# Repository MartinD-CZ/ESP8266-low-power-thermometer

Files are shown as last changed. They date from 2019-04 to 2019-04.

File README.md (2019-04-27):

# ESP8266 ultra low power thermometer
*see the article [here](http://embedblog.eu/?p=36)*
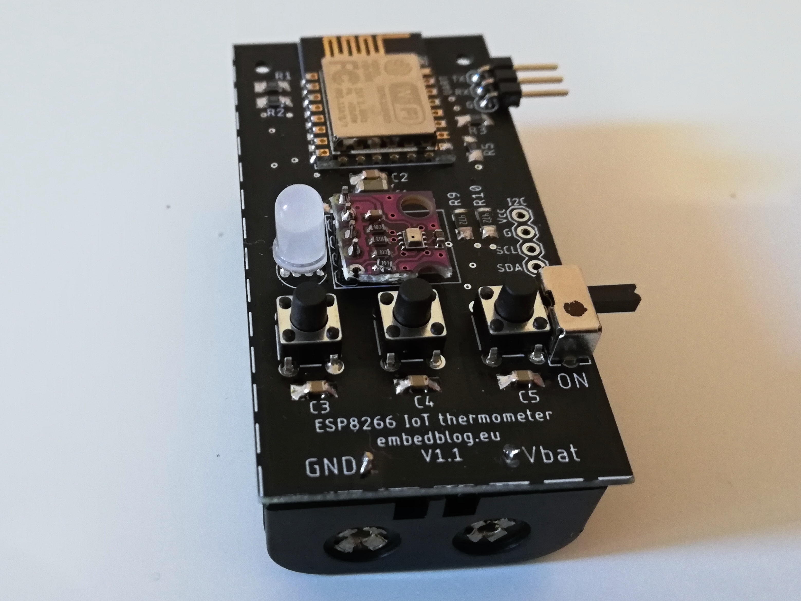
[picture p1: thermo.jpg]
A picture of the finished thermometer


## Specs
1. Arduino-compatible
2. lasts more than 2 years on a pair of AA batteries
3. measures temperature and pressure (BMP280) OR temperature, humidity and pressure (BME280)
4. transmits data regularly to Blynk (or other platform, if you program it for it)
5. can be programmed with just a simple USB-Serial converter

## Required libraries
* [ESP8266 core](https://github.com/esp8266/Arduino)
* [Blynk library](https://github.com/blynkkk/blynk-library)
* [BMP280 library](https://github.com/mahfuz195/BMP280-Arduino-Library)

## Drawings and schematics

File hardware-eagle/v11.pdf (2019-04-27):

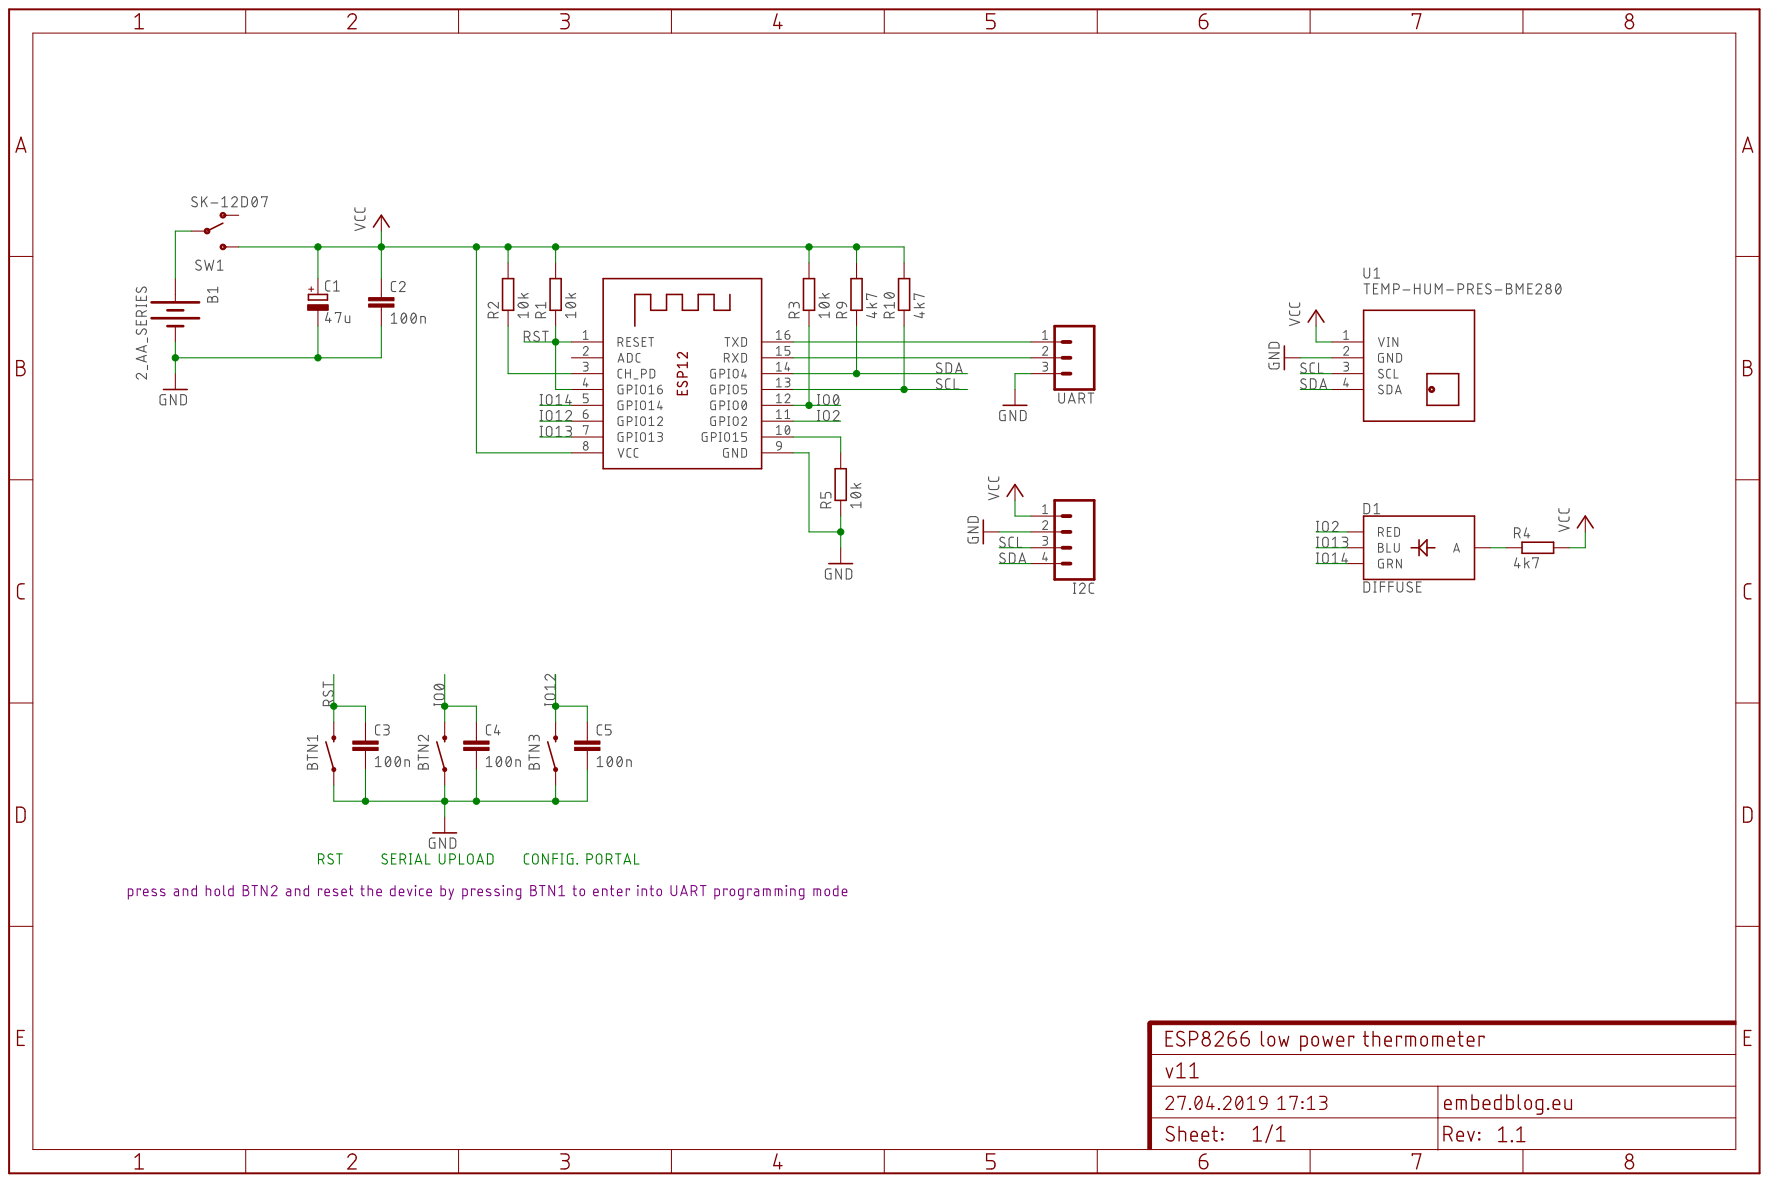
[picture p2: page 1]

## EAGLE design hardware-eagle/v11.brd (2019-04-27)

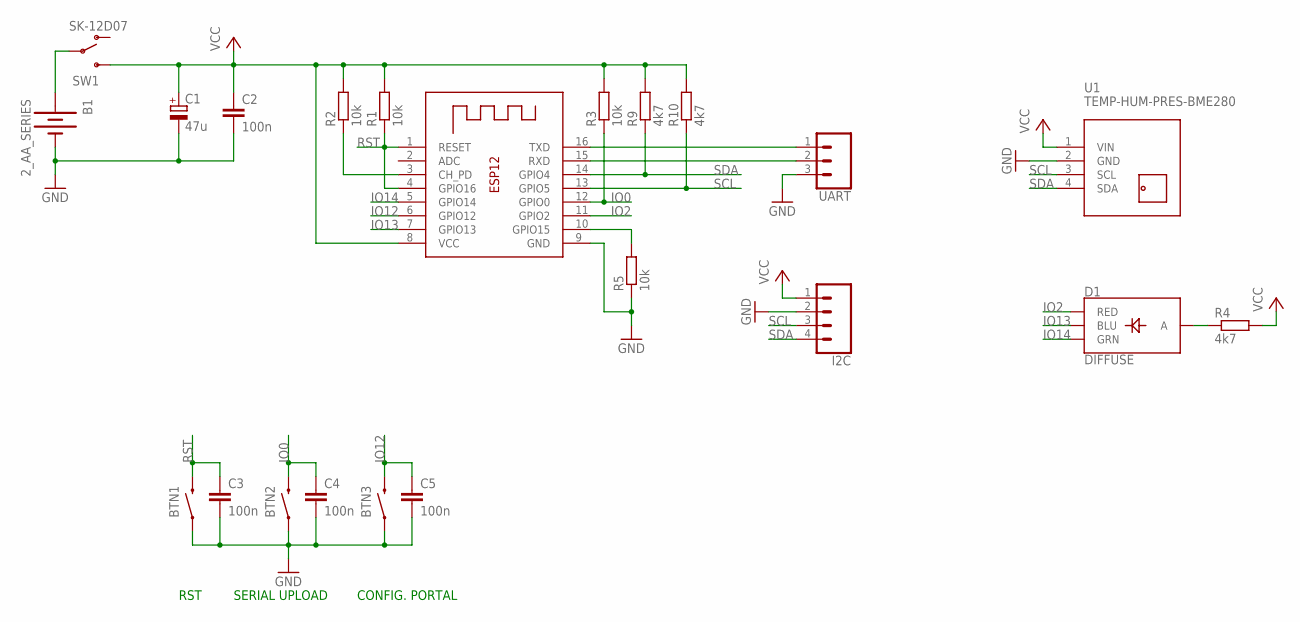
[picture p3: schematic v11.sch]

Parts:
B1: 2_AA_SERIES; AA_HOLDER_BH-321-1P
BTN1, BTN2, BTN3: MOMENTARY-SWITCH-SPST-PTH-6.0MM; TACTILE_SWITCH_PTH_6.0MM
C1: 47u; SMC_B
C2, C3, C4, C5: 100n; C1206
D1: DIFFUSE; LED-RGB-THRU
I2C: CONN_04; 1X04
R1, R2, R3, R5: 10k; R1206
R4, R9, R10: 4k7; R1206
SW1: SK-12D07; SK12SWITCH
U1: TEMP-HUM-PRES-BME280
UART: 455-1750-1-ND; 1X03
X1: ESP-12

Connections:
GND: B1.NEG (-), BTN1.1, BTN2.1, BTN3.1, C1.-, C2.2, C3.2, C4.2, C5.2, I2C.2, R5.1, U1.2 (GND), UART.3, X1.9 (GND)
IO0: BTN2.3 (2), C4.1, R3.1, X1.12 (GPIO0)
IO2: D1.1 (RED), X1.11 (GPIO2)
IO12: BTN3.3 (2), C5.1, X1.6 (GPIO12)
IO13: D1.4 (BLU), X1.7 (GPIO13)
IO14: D1.3 (GRN), X1.5 (GPIO14)
unnamed: D1.2 (A), R4.1
unnamed: R2.1, X1.3 (CH_PD)
unnamed: R5.2, X1.10 (GPIO15)
unnamed: B1.POS (+), SW1.P2
RST: BTN1.3 (2), C3.1, R1.1, X1.1 (RESET), X1.4 (GPIO16)
RX: UART.2, X1.15 (RXD)
SCL: I2C.3, R10.1, U1.3 (SCL), X1.13 (GPIO5)
SDA: I2C.4, R9.1, U1.4 (SDA), X1.14 (GPIO4)
TX: UART.1, X1.16 (TXD)
VCC: C1.+, C2.1, I2C.1, R1.2, R2.2, R3.2, R4.2, R9.2, R10.2, SW1.IN (S), U1.1 (VIN), X1.8 (VCC)

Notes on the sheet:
RST
SERIAL UPLOAD
CONFIG. PORTAL

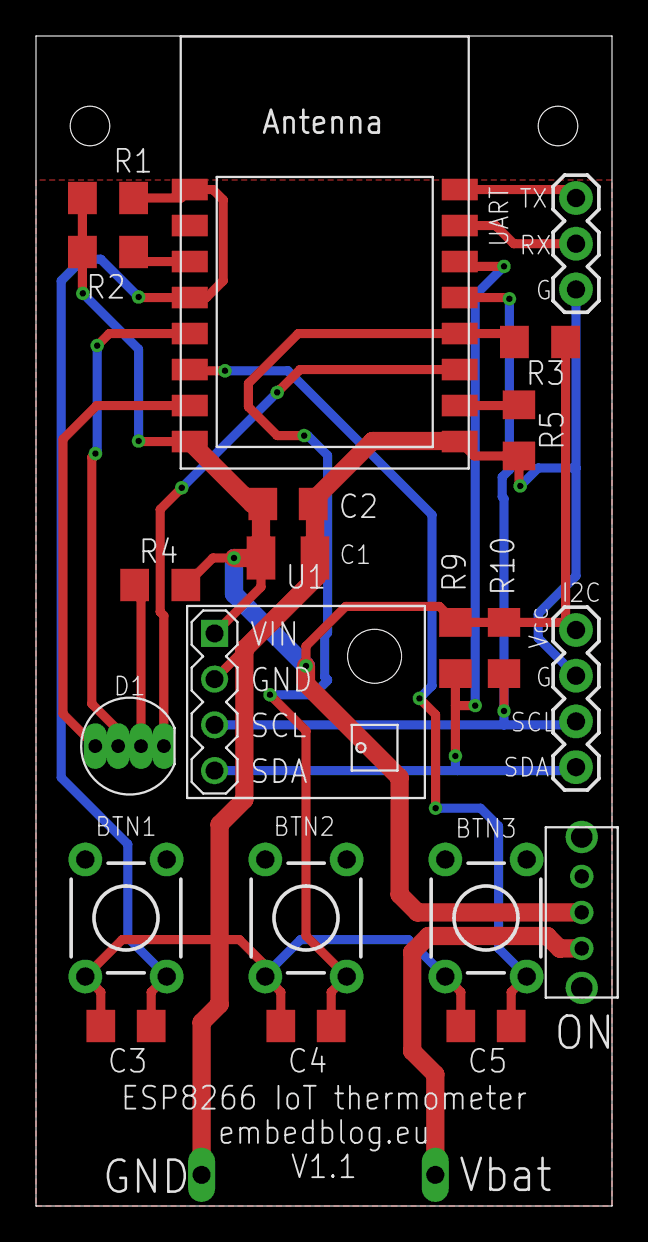
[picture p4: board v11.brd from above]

Board: 2 copper layers, 32.0 x 65.0 mm, 22 parts (1 on the bottom side), 16 nets.

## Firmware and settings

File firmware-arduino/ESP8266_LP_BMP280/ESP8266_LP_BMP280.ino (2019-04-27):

#define DEBUG_SERIAL
#ifdef DEBUG_SERIAL
#define DBG_PRINT(x)    Serial.print(x)
#define DBG_PRINTLN(x)  Serial.println(x)
#define BLYNK_PRINT Serial
#else
#define DBG_PRINT(x)
#define DBG_PRINTLN(x)
#endif

#include <ESP8266WiFi.h>
#include <BlynkSimpleEsp8266.h>

#include <Wire.h>
#include "BMP280.h"
BMP280 bmp;

#define RTC_VALID_DATA  0xC4
typedef struct rtc {
  uint8_t dataValidation;
  int32_t messageID;
};
rtc rtcMem;

ADC_MODE(ADC_VCC);

// CONFIG PART
// modify the below to set parameters

#define DEEPSLEEP_INTERVAL    60    //in minutes
#define MSGID_VWIRE           V0
#define BATT_VWIRE            V1
#define TEMP_VWIRE            V2
#define HUM_VWIRE             V3
#define PRES_VWIRE            V4

char* ssid = "";
char* pass = "";
char* auth = "";

void setup() 
{
  gpio_init();
  DBG_PRINTLN("");
  DBG_PRINTLN("Device started");

  if (bmp.begin(5, 4))
    {
      DBG_PRINTLN("BMP/BME sensor successfully initialized");
      bmp.setOversampling(4);
    }
    else
    {
      DBG_PRINTLN("BMP/BME sensor not found!");
      deepSleep();
    }

  DBG_PRINT("Battery voltage: ");
  float Vbat = ESP.getVcc() / 1000.0f;
  DBG_PRINT(Vbat);
  DBG_PRINTLN(" V");

  DBG_PRINT("Reading RTC Memory...");
  ESP.rtcUserMemoryRead(0, (uint32_t*)&rtcMem, sizeof(rtcMem));
  if (rtcMem.dataValidation == RTC_VALID_DATA)
  {
    DBG_PRINT("Found valid message ID: ");
    DBG_PRINTLN(rtcMem.messageID);
  }
  else
  {
    DBG_PRINTLN("No valid data in RTC found, message ID set to 0");
    rtcMem.messageID = 0;
  }
  rtcMem.dataValidation = RTC_VALID_DATA;

  if (startMeasurement())
    DBG_PRINTLN("Reading data from sensor...");
  else
  {
    DBG_PRINTLN("Error reading from sensor...");
    deepSleep();
  }

  DBG_PRINTLN("Configuring Blynk...");
  WiFi.forceSleepWake();
  delay(1);
  WiFi.persistent(false);
  WiFi.mode(WIFI_STA);
  //WiFi.config(ip, gateway, subnet);
  Blynk.begin(auth, ssid, pass);
  if (Blynk.connected())
    led_green();
  else
    led_red();
  
  Blynk.virtualWrite(MSGID_VWIRE, rtcMem.messageID++);
  Blynk.virtualWrite(BATT_VWIRE, Vbat);
  Blynk.virtualWrite(TEMP_VWIRE, getTemperature());
  //Blynk.virtualWrite(HUM_VWIRE, getHumidity());
  Blynk.virtualWrite(PRES_VWIRE, getPressure());
  
  Blynk.run();

  ESP.rtcUserMemoryWrite(0, (uint32_t*) &rtcMem, sizeof(rtcMem));
  DBG_PRINTLN("RTC data saved.");

  delay(300);
  led_none();

  deepSleep();
}

void loop() {}

void deepSleep()
{
  led_none();
  DBG_PRINT("Going to deep sleep");
  ESP.deepSleep(DEEPSLEEP_INTERVAL * 60 * 1e6);
  while (1)
  {
    DBG_PRINT(".");
    delay(100);
  }
}

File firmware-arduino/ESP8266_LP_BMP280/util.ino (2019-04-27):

double temperature, pressure;

void gpio_init()
{
  pinMode(2, OUTPUT);
  pinMode(13, OUTPUT);
  pinMode(14, OUTPUT);
  led_none();
  Serial.begin(115200);
  
}

void led_red()
{
  digitalWrite(2, LOW);
  digitalWrite(13, HIGH);
  digitalWrite(14, HIGH);
}

void led_green()
{
  digitalWrite(2, HIGH);
  digitalWrite(13, HIGH);
  digitalWrite(14, LOW);
}

void led_blue()
{
  digitalWrite(2, HIGH);
  digitalWrite(13, LOW);
  digitalWrite(14, HIGH);
}

void led_none()
{
  digitalWrite(2, HIGH);
  digitalWrite(13, HIGH);
  digitalWrite(14, HIGH);
}

bool startMeasurement()
{
  uint8_t result = bmp.startMeasurment();
  if (result != 0)
  {
    delay(result);
    result = bmp.getTemperatureAndPressure(temperature, pressure);
    if (result != 0)
      return 1;
    else
      return 0;
  }
  else
    return 0;
}

float getTemperature()
{
  return (temperature);
}

float getHumidity()
{
  return random(0, 100);
}

uint16_t getPressure()
{
  return pressure;
}

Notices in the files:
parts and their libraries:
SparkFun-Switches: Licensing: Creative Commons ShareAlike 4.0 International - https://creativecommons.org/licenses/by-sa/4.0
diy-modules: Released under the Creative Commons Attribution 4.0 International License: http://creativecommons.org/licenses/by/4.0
